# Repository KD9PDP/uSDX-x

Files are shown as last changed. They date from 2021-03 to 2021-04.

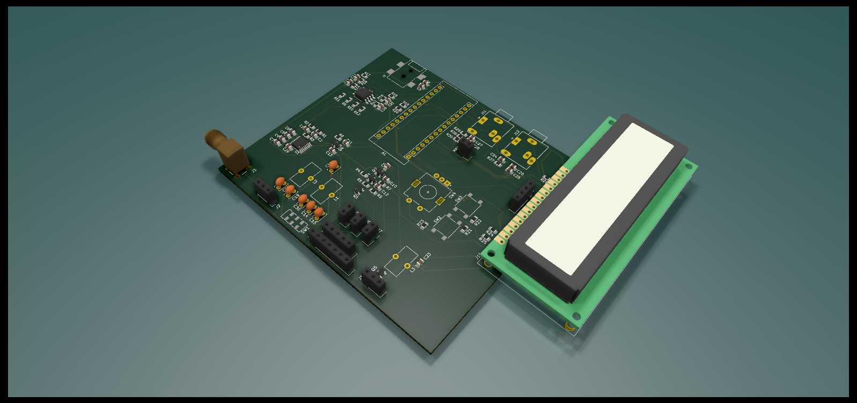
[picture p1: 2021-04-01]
uSDX-x.png

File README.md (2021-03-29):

# uSDX-x
uSDX-x: Microcontroller SDR QRP Transceiver Designed for Experimentation

The goal of this project is to make an uSDX platform that:
* Is Open Hardware Licensed: [TAPR Open Hardware License](https://tapr.org/the-tapr-open-hardware-license/)
* Is modular such that you can use the default on board components or easily add your own
  * Default 1 band on board, but can also add on filter modules for other bands (can experiment with filter modules)
  * Either a 1602 LCD or any LCD using I2C/TWI (e.g., OLED)
  * On board single PA MOSFET or connector for your own experimental evaluation of different MOSFETs (e.g., 3x parallel BS170s)
* Exposes all the key nodes in a way that you can just plug in an Arduino nano module to control them, or you can experiment with other MCU development boards (e.g., 32-bit MCU from various manufacturers such as ARM Cortex-M based MCUs).
* "Semiconductor shortage friendly" (uses si5351 modules instead of chips, which are sold out everywhere until 2022)
  * Contains connectors both for the Adafruit and Etherkit style si5351 modules.
* Compatible with jlcpcb PCBA for low-cost PCB manufacturing and assembly
  * Maximize usage of "basic" parts (e.g., uses a BJT gate driver instead of a 74ACT logic gate driver, possibly with improved performance. NE5532 for the AF op amp instead of LM4562.)

This is based on and compatible with:
https://github.com/threeme3/QCX-SSB
by Guido (PE1NNZ)

For more info on development of uSDX platforms, see: https://groups.io/g/ucx

Two other excellent boards:
https://groups.io/g/ucx/wiki/23416 by Barbaros Asuroglu (WB2CBA)
and
https://dl2man.de/ by Manual (DL2MAN)

Copyright 2021
Scott Howard KD9PDP

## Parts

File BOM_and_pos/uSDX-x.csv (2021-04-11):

Comment | Designator | Footprint | LCSC
Arduino Nano | A1 | Module:Arduino_Nano | no assembly
10n | C2,C11,C12,C13,C27 | Capacitor_SMD:C_0805_2012Metric_Pad1.15x1.40mm_HandSolder | C1710
150p | C14 | Capacitor_THT:C_Disc_D3.8mm_W2.6mm_P2.50mm | no assembly
56p | C15 | Capacitor_THT:C_Disc_D3.8mm_W2.6mm_P2.50mm | no assembly
1n | C16,C17 | Capacitor_SMD:C_0805_2012Metric_Pad1.15x1.40mm_HandSolder | C46653
240p | C18 | Capacitor_THT:C_Disc_D3.8mm_W2.6mm_P2.50mm | no assembly
82p | C19 | Capacitor_THT:C_Disc_D3.8mm_W2.6mm_P2.50mm
220p | C20 | Capacitor_THT:C_Disc_D3.8mm_W2.6mm_P2.50mm | no assembly
10u | C3,C24 | Capacitor_SMD:C_0805_2012Metric_Pad1.15x1.40mm_HandSolder | C15850
200p | C30 | Capacitor_THT:C_Disc_D3.8mm_W2.6mm_P2.50mm | no assembly
100n | C1,C4,C5,C10,C21,C22,C23,C25,C26,C28,C29 | Capacitor_SMD:C_0805_2012Metric_Pad1.15x1.40mm_HandSolder | C49678
470n | C6,C7,C8,C9 | Capacitor_SMD:C_0805_2012Metric_Pad1.15x1.40mm_HandSolder | C13967
DC Jack | J1 | uSDX-x:BarrelJack_XKB_DC-005-5A-2.0-SMT_Horizontal | C319134
1602LCD | J10 | Display:WC1602A | no assembly
PJ-324M | J11,J12 | Connector_Audio:Jack_3.5mm_Ledino_KB3SPRS_Horizontal | no assembly
PA MOSFETs | J13 | Connector_PinSocket_2.54mm:PinSocket_1x03_P2.54mm_Vertical | no assembly
FilterConn | J2 | Connector_PinSocket_2.54mm:PinSocket_1x03_P2.54mm_Vertical | no assembly
Antenna | J3 | eec:Molex-73100-0114-0-0-0 | no assembly
Etherkit si5351 | J4 | Connector_PinSocket_2.54mm:PinSocket_1x05_P2.54mm_Vertical | no assembly
EK CLK0 | J5 | Connector_PinSocket_2.54mm:PinSocket_1x02_P2.54mm_Vertical | no assembly
EK CLK1 | J6 | Connector_PinSocket_2.54mm:PinSocket_1x02_P2.54mm_Vertical | no assembly
EK CLK2 | J7 | Connector_PinSocket_2.54mm:PinSocket_1x02_P2.54mm_Vertical | no assembly
Adafruit si5351 | J8 | Connector_PinSocket_2.54mm:PinSocket_1x07_P2.54mm_Vertical | no assembly
SSD1306 OLED and I2C out | J9 | Connector_PinSocket_2.54mm:PinSocket_1x04_P2.54mm_Vertical | no assembly
12T/T37-6 | L1 | Inductor_THT:L_Toroid_Vertical_L10.0mm_W5.0mm_P5.08mm | no assembly
8T/T37-6 | L2 | Inductor_THT:L_Toroid_Vertical_L10.0mm_W5.0mm_P5.08mm | no assembly
22T/FT37-43 | L3 | Inductor_THT:L_Toroid_Vertical_L10.0mm_W5.0mm_P5.08mm | no assembly
Condenser Mic | MK1 | Connector_PinSocket_2.54mm:PinSocket_1x02_P2.54mm_Vertical | no assembly
S9013 | Q1,Q2 | Package_TO_SOT_SMD:SOT-23 | C6749
S9012 | Q3 | Package_TO_SOT_SMD:SOT-23 | C8543
2N7002 | Q4 | Package_TO_SOT_SMD:SOT-23 | C8545
IRLML2060 | Q5 | Package_TO_SOT_SMD:SOT-23 | C67275
82k | R13,R14 | Resistor_SMD:R_0805_2012Metric_Pad1.15x1.40mm_HandSolder | C17840
1k | R3,R8,R19,R20,R22,R24,R25,R26 | Resistor_SMD:R_0805_2012Metric_Pad1.15x1.40mm_HandSolder | C17513
3k3 | R21 | Resistor_SMD:R_0805_2012Metric_Pad1.15x1.40mm_HandSolder | C26010
270R | R27 | Resistor_SMD:R_0805_2012Metric_Pad1.15x1.40mm_HandSolder | C17590
47R | R4 | Resistor_SMD:R_0805_2012Metric_Pad1.15x1.40mm_HandSolder | C17561
22R | R5 | Resistor_SMD:R_0805_2012Metric_Pad1.15x1.40mm_HandSolder | C17958
10k | R1,R2,R6,R7,R15,R16,R17,R18,R23,R28,R29,R30 | Resistor_SMD:R_0805_2012Metric_Pad1.15x1.40mm_HandSolder | C17414
100R | R9,R10,R11,R12 | Resistor_SMD:R_0805_2012Metric_Pad1.15x1.40mm_HandSolder | C17408
SW_DPDT_x2 | SW1 | Button_Switch_SMD:SW_DPDT_CK_JS202011JCQN | C145844
L | SW2 | Button_Switch_SMD:SW_Push_1P1T_NO_6x6mm_H9.5mm | C480275
R | SW3 | Button_Switch_SMD:SW_Push_1P1T_NO_6x6mm_H9.5mm | C480275
Rotary Encoder | SW4 | Rotary_Encoder:RotaryEncoder_Alps_EC11E-Switch_Vertical_H20mm | no assembly
SN74CBT3253PWR | U1 | Package_SO:TSSOP-16_4.4x5mm_P0.65mm | C424399
NE5532DR | U2 | Package_SO:SOIC-8_5.275x5.275mm_P1.27mm | C7426

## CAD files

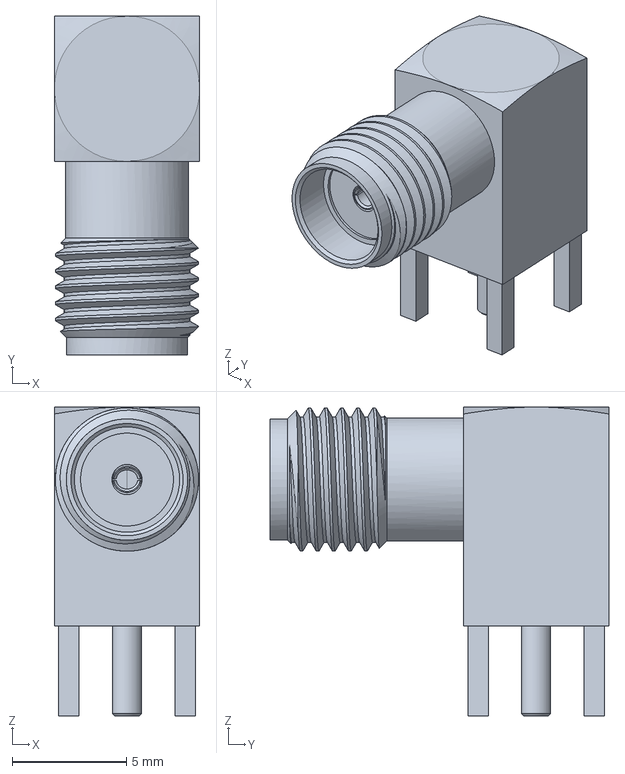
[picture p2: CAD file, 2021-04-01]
extraLibs/eec.models/Molex_-_73100-0114_ssh.stp
6.35 x 14.8 x 13.5 mm

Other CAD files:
extraLibs/eec.models/Molex_-_73100-0114.step

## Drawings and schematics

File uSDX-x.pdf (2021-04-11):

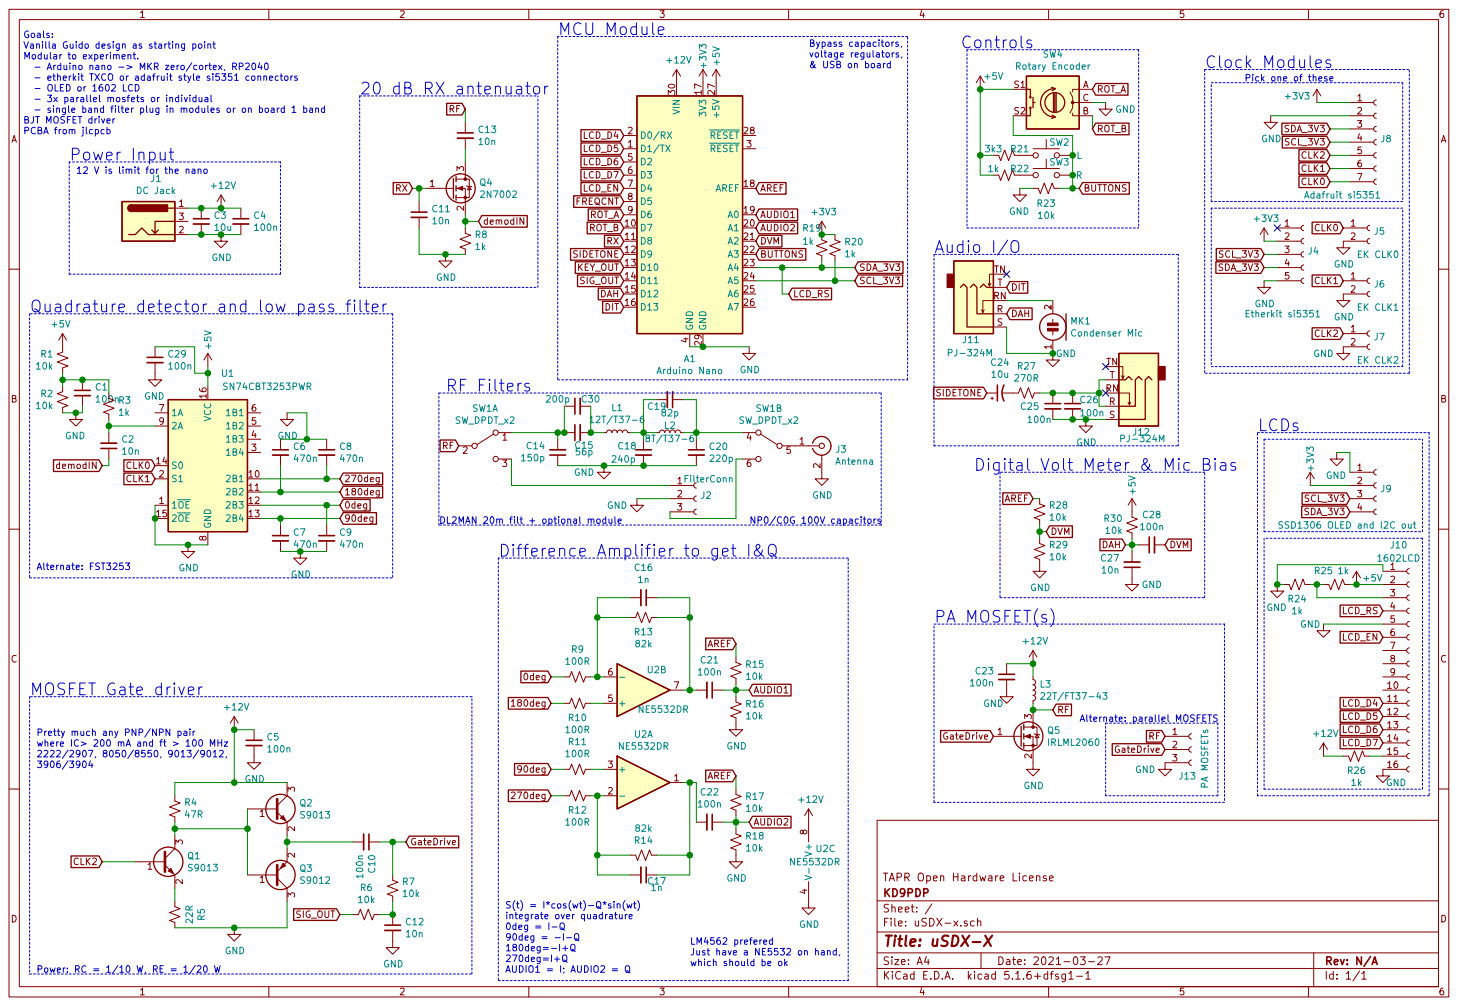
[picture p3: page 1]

LCD_EN Goals: Vanilla Guido design as starting point
2N7002 GND

Modular to experiment.
- Arduino nano -> MKR zero/cortex, RP2040
- etherkit TXCO or adafruit style si5351 connectors
- OLED or 1602 LCD
- 3x parallel mosfets or individual
- single band filter plug in modules or on board 1 band BJT MOSFET driver PCBA from jlcpcb

Just have a NE5532 on hand, which should be ok Quadrature detector and low pass filter

J9 SSD1306 OLED and I2C out GND

AUDIO1 = I; AUDIO2 = Q Difference Amplifier to get I&Q

TAPR Open Hardware License
File: uSDX-x.sch Sheet: / KD9PDP

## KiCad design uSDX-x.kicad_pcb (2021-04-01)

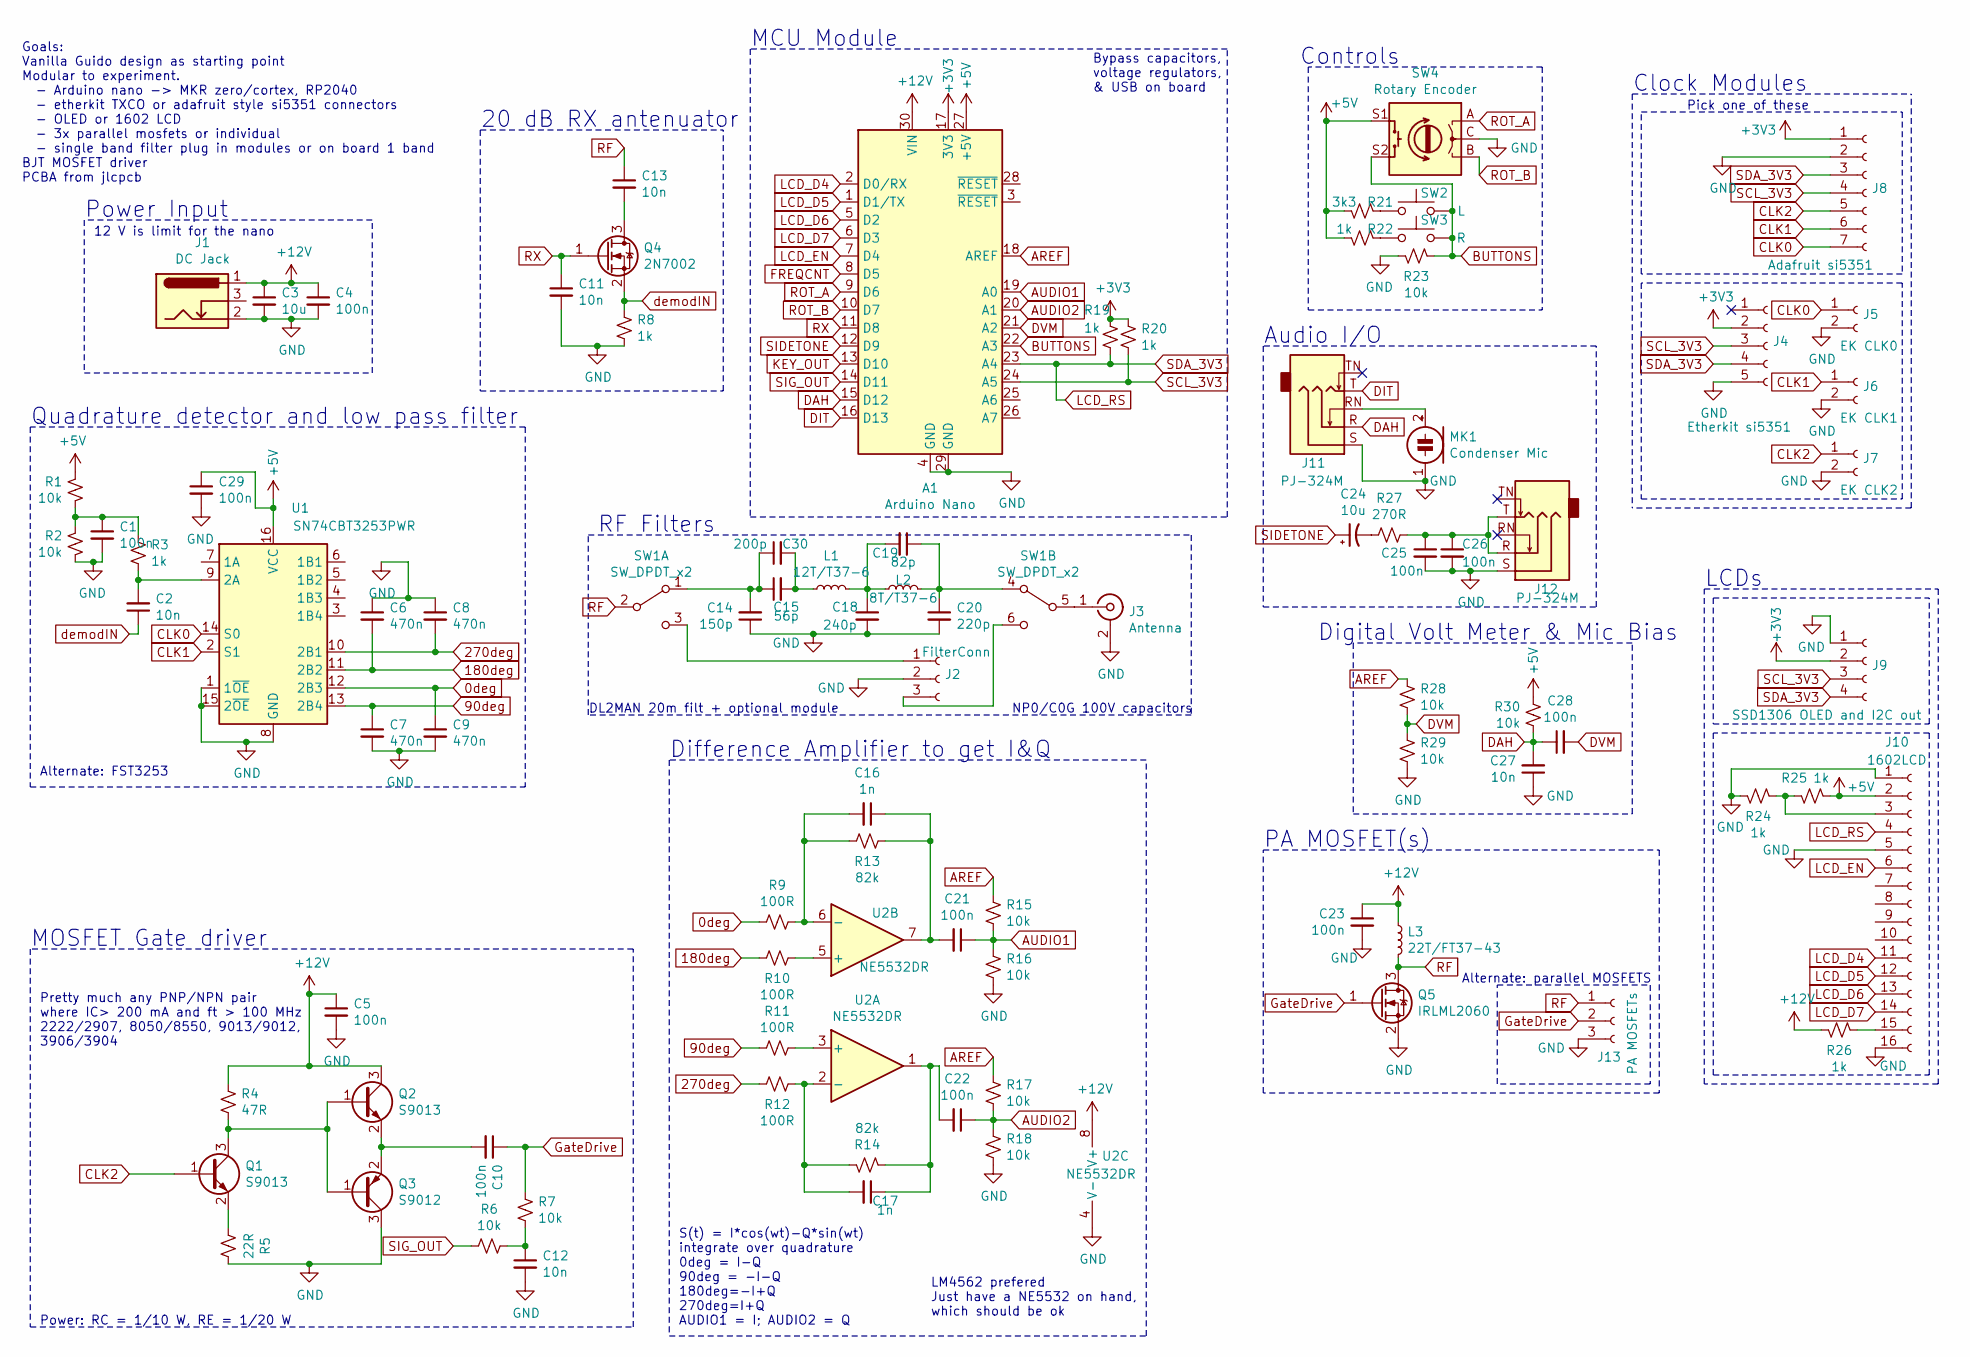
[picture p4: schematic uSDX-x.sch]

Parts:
A1: Arduino Nano; Arduino_Nano; LCSC no assembly
C1, C4, C5, C10, C21, C22, C23, C25, C26, C28, C29: 100n; C_0805_2012Metric_Pad1.15x1.40mm_HandSolder; LCSC C49678
C2, C11, C12, C13, C27: 10n; C_0805_2012Metric_Pad1.15x1.40mm_HandSolder; LCSC C1710
C3, C24: 10u; C_0805_2012Metric_Pad1.15x1.40mm_HandSolder; LCSC C15850
C6, C7, C8, C9: 470n; C_0805_2012Metric_Pad1.15x1.40mm_HandSolder; LCSC C13967
C14: 150p; C_Disc_D3.8mm_W2.6mm_P2.50mm; LCSC no assembly
C15: 56p; C_Disc_D3.8mm_W2.6mm_P2.50mm; LCSC no assembly
C16, C17: 1n; C_0805_2012Metric_Pad1.15x1.40mm_HandSolder; LCSC C46653
C18: 240p; C_Disc_D3.8mm_W2.6mm_P2.50mm; LCSC no assembly
C19: 82p; C_Disc_D3.8mm_W2.6mm_P2.50mm
C20: 220p; C_Disc_D3.8mm_W2.6mm_P2.50mm; LCSC no assembly
C30: 200p; C_Disc_D3.8mm_W2.6mm_P2.50mm; LCSC no assembly
J1: DC Jack; BarrelJack_XKB_DC-005-5A-2.0-SMT_Horizontal; LCSC C319134
J2: FilterConn; PinSocket_1x03_P2.54mm_Vertical; LCSC no assembly
J3: Antenna; Molex-73100-0114-0-0-0; LCSC no assembly
J4: Etherkit si5351; PinSocket_1x05_P2.54mm_Vertical; LCSC no assembly
J5: EK CLK0; PinSocket_1x02_P2.54mm_Vertical; LCSC no assembly
J6: EK CLK1; PinSocket_1x02_P2.54mm_Vertical; LCSC no assembly
J7: EK CLK2; PinSocket_1x02_P2.54mm_Vertical; LCSC no assembly
J8: Adafruit si5351; PinSocket_1x07_P2.54mm_Vertical; LCSC no assembly
J9: SSD1306 OLED and I2C out; PinSocket_1x04_P2.54mm_Vertical; LCSC no assembly
J10: 1602LCD; WC1602A; LCSC no assembly
J11, J12: PJ-324M; Jack_3.5mm_Ledino_KB3SPRS_Horizontal; LCSC no assembly
J13: PA MOSFETs; PinSocket_1x03_P2.54mm_Vertical; LCSC no assembly
L1: 12T/T37-6; L_Toroid_Vertical_L10.0mm_W5.0mm_P5.08mm; LCSC no assembly
L2: 8T/T37-6; L_Toroid_Vertical_L10.0mm_W5.0mm_P5.08mm; LCSC no assembly
L3: 22T/FT37-43; L_Toroid_Vertical_L10.0mm_W5.0mm_P5.08mm; LCSC no assembly
MK1: Condenser Mic; PinSocket_1x02_P2.54mm_Vertical; LCSC no assembly
Q1, Q2: S9013; SOT-23; LCSC C6749
Q3: S9012; SOT-23; LCSC C8543
Q4: 2N7002; SOT-23; LCSC C8545
Q5: IRLML2060; SOT-23; LCSC C67275
R1, R2, R6, R7, R15, R16, R17, R18, R23, R28, R29, R30: 10k; R_0805_2012Metric_Pad1.15x1.40mm_HandSolder; LCSC C17414
R3, R8, R19, R20, R22, R24, R25, R26: 1k; R_0805_2012Metric_Pad1.15x1.40mm_HandSolder; LCSC C17513
R4: 47R; R_0805_2012Metric_Pad1.15x1.40mm_HandSolder; LCSC C17561
R5: 22R; R_0805_2012Metric_Pad1.15x1.40mm_HandSolder; LCSC C17958
R9, R10, R11, R12: 100R; R_0805_2012Metric_Pad1.15x1.40mm_HandSolder; LCSC C17408
R13, R14: 82k; R_0805_2012Metric_Pad1.15x1.40mm_HandSolder; LCSC C17840
R21: 3k3; R_0805_2012Metric_Pad1.15x1.40mm_HandSolder; LCSC C26010
R27: 270R; R_0805_2012Metric_Pad1.15x1.40mm_HandSolder; LCSC C17590
SW1: SW_DPDT_x2; SW_DPDT_CK_JS202011JCQN; LCSC C145844
SW2: L; SW_Push_1P1T_NO_6x6mm_H9.5mm; LCSC C480275
SW3: R; SW_Push_1P1T_NO_6x6mm_H9.5mm; LCSC C480275
SW4: Rotary Encoder; RotaryEncoder_Alps_EC11E-Switch_Vertical_H20mm; LCSC no assembly
U1: SN74CBT3253PWR; TSSOP-16_4.4x5mm_P0.65mm; LCSC C424399
U2: NE5532DR; SOIC-8_5.275x5.275mm_P1.27mm; LCSC C7426

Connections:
0deg: C9.1, R9.1, U1.12 (2B3)
90deg: C7.1, R11.1, U1.13 (2B4)
180deg: C6.2, R10.1, U1.11 (2B2)
270deg: C8.2, R12.1, U1.10 (2B1)
+3V3: A1.17 (3V3), J4.2, J8.1, J9.2, R19.1, R20.1
+5V: A1.27 (+5V), C29.1, J10.2, R1.1, R21.1, R22.1, R25.1, R30.2, SW4.S1, U1.16 (VCC)
+12V: A1.30 (VIN), C3.1, C4.1, C5.1, C23.1, J1.1, L3.1, Q2.3 (C), R4.2, R26.2, U2.8 (V+)
AREF: A1.18 (AREF), R15.1, R17.1, R28.2
AUDIO1: A1.19 (A0), C21.1, R15.2, R16.1
AUDIO2: A1.20 (A1), C22.1, R17.2, R18.1
BUTTONS: A1.22 (A3), R23.2, SW2.1, SW3.1, SW4.S2
CLK0: J5.1, J8.7, U1.14 (S0)
CLK1: J6.1, J8.6, U1.2 (S1)
CLK2: J7.1, J8.5, Q1.1 (B)
DAH: A1.15 (D12), C27.2, C28.1, J11.R, R30.1
DIT: A1.16 (D13), J11.T
DVM: A1.21 (A2), C28.2, R28.1, R29.2
FREQCNT: A1.8 (D5)
GND: A1.4 (GND), A1.29 (GND), C1.2, C3.2, C4.2, C5.2, C6.1, C7.2, C8.1, C9.2, C11.2, C12.2, C14.1, C18.2, C20.2, C23.2, C25.2, C26.2, C27.1, C29.2, J1.2, J2.2, J3.2 (Ext), J4.5, J5.2, J6.2, J7.2, J8.2, J9.1, J10.1, J10.5, J10.16, J11.S, J12.S, J13.3, MK1.1 (-), Q3.3 (C), Q5.2 (S), R2.2, R5.1, R8.1, R16.2, R18.2, R23.1, R24.2, R29.1, SW4.C, U1.1 (1~OE), U1.8 (GND), U1.15 (2~OE), U2.4 (V-)
GateDrive: C10.1, J13.2, Q5.1 (G), R7.2
KEY_OUT: A1.13 (D10)
LCD_D4: A1.2 (D0/RX), J10.11
LCD_D5: A1.1 (D1/TX), J10.12
LCD_D6: A1.5 (D2), J10.13
LCD_D7: A1.6 (D3), J10.14
LCD_EN: A1.7 (D4), J10.6
LCD_RS: A1.23 (A4), J4.4, J8.3, J9.4, J10.4, R19.2
unnamed: C1.1, R1.2, R2.1, R3.1
unnamed: C2.2, R3.2, U1.9 (2A)
unnamed: C10.2, Q2.2 (E), Q3.2 (E)
unnamed: C12.1, R6.1, R7.1
unnamed: C13.2, Q4.3 (D)
unnamed: C14.2, C15.1, C30.1, SW1.1 (A)
unnamed: C15.2, C30.2, L1.1
unnamed: C16.1, C21.2, R13.2, U2.7
unnamed: C16.2, R9.2, R13.1, U2.6 (-)
unnamed: C17.1, C22.2, R14.2, U2.1
unnamed: C17.2, R12.2, R14.1, U2.2 (-)
unnamed: C18.1, C19.2, L1.2, L2.1
unnamed: C19.1, C20.1, L2.2, SW1.4 (A)
unnamed: C24.2, R27.2
unnamed: C25.1, C26.1, J12.R, J12.T, R27.1
unnamed: J2.1, SW1.3 (C)
unnamed: J2.3, SW1.6 (C)
unnamed: J3.1 (In), SW1.5 (B)
unnamed: J10.3, R24.1, R25.2
unnamed: J10.15, R26.1
unnamed: J11.RN, MK1.2 (+)
unnamed: Q1.2 (E), R5.2
unnamed: Q1.3 (C), Q2.1 (B), Q3.1 (B), R4.1
unnamed: R10.2, U2.5 (+)
unnamed: R11.2, U2.3 (+)
unnamed: R21.2, SW2.2
unnamed: R22.2, SW3.2
RF: C13.1, J13.1, L3.2, Q5.3 (D), SW1.2 (B)
ROT_A: A1.9 (D6), SW4.A
ROT_B: A1.10 (D7), SW4.B
RX: A1.11 (D8), C11.1, Q4.1 (G)
SCL_3V3: A1.24 (A5), J4.3, J8.4, J9.3, R20.2
SIDETONE: A1.12 (D9), C24.1
SIG_OUT: A1.14 (D11), R6.2
demodIN: C2.1, Q4.2 (S), R8.2

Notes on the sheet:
Goals: Vanilla Guido design as starting point Modular to experiment. - Arduino nano -> MKR zero/cortex, RP2040 - etherkit TXCO or adafruit style si5351 connectors - OLED or 1602 LCD - 3x parallel mosfets or individual - single band filter plug in modules or on board 1 band BJT MOSFET driver PCBA fr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
12 V is limit for the nano
Pretty much any PNP/NPN pair where IC> 200 mA and ft > 100 MHz 2222/2907, 8050/8550, 9013/9012, 3906/3904
MOSFET Gate driver
Power Input
PA MOSFET(s)
20 dB RX antenuator
Quadrature detector and low pass filter
S(t) = I*cos(wt)-Q*sin(wt) integrate over quadrature 0deg = I-Q 90deg = -I-Q 180deg=-I+Q 270deg=I+Q AUDIO1 = I; AUDIO2 = Q
Difference Amplifier to get I&Q
Controls
MCU Module
RF Filters
LCDs
LM4562 prefered Just have a NE5532 on hand, which should be ok
Alternate: FST3253
Digital Volt Meter & Mic Bias
Audio I/O
Power: RC = 1/10 W, RE = 1/20 W
NP0/C0G 100V capacitors
DL2MAN 20m filt + optional module
Alternate: parallel MOSFETS
Bypass capacitors, voltage regulators, & USB on board
Pick one of these
Clock Modules

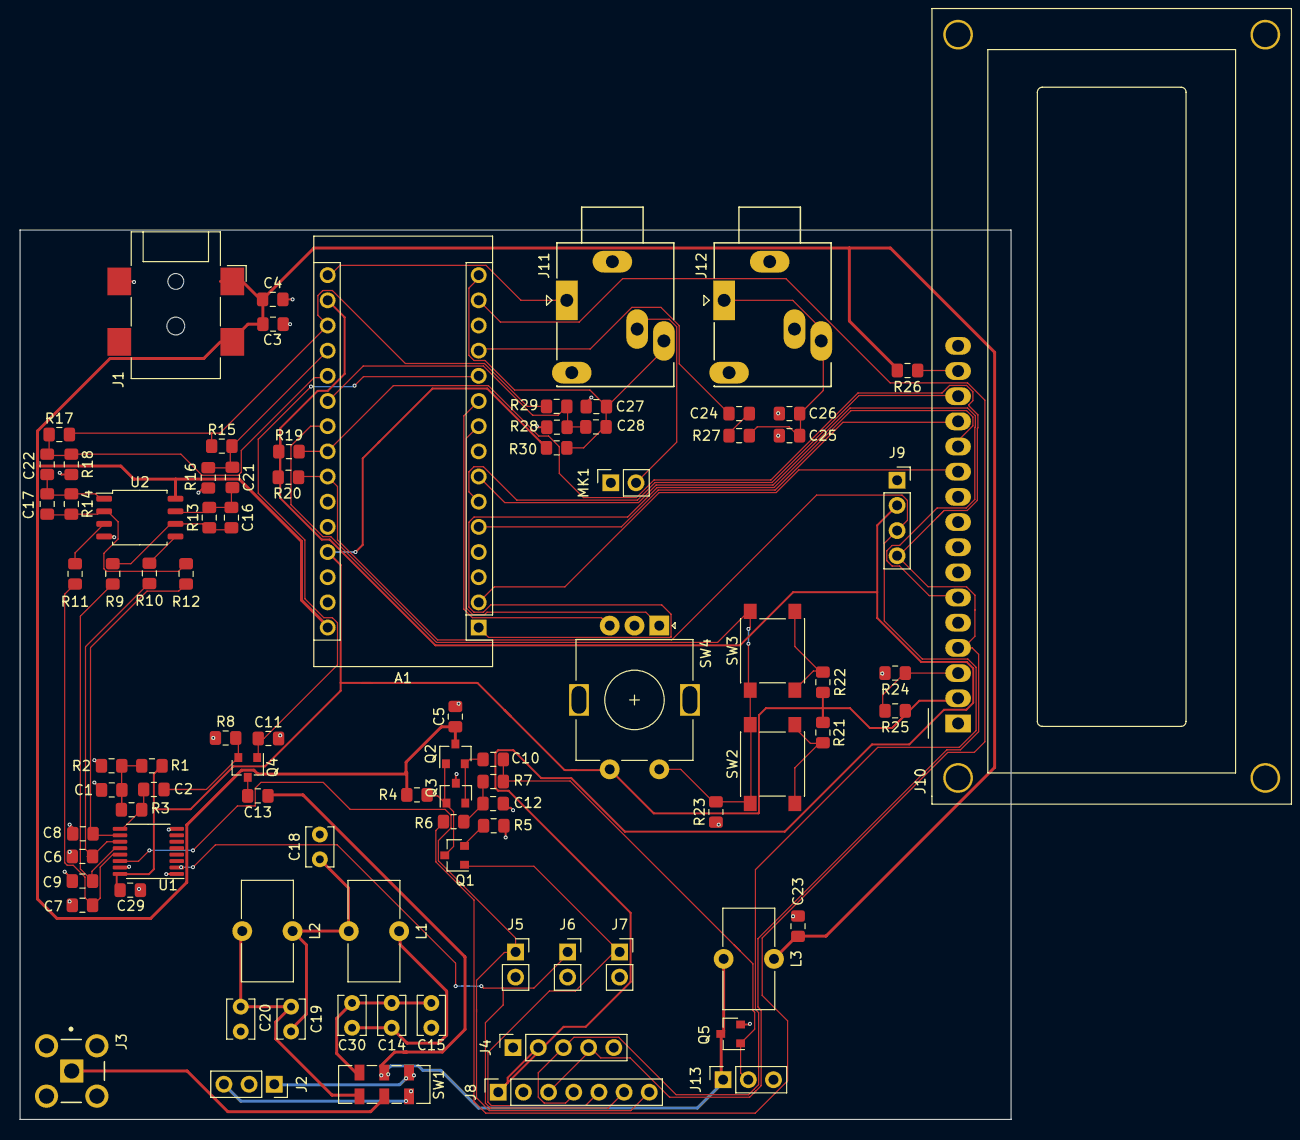
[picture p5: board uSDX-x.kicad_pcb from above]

Board: 2 copper layers, 100.0 x 89.8 mm, 89 parts (0 on the bottom side), 60 nets.

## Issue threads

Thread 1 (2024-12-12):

Prototype made. No display after switch on.

mmagit-it, 2024-12-12:
I've made a prototype of uSDX-x using 1602 display . Unfortunately after switch on display is off.
I've checked all voltages (+12Vdc, +5V, +3.3V) all is ok.
I've programmed Arduino nano with 1.02w and 1.02x versions. Same results.
Any other debugging suggestions are welcome.
Thank you in advance.
Maurizio.
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

maqifrnswa, 2024-12-12:
Sorry, I haven't made it with this MCU and switched over to another
architecture (rp2040 from the raspberry pi pico, a dual core arm cortex m0+
at 125 MHz with integrated USB). That chip architecture was released while
I was working in this repo

See projects doing that here:
https://github.com/ArjanteMarvelde/uSDR-pico
https://github.com/kaefe64/Arduino_uSDX_Pico_FFT_Proj

The rp2040 has programmable IO which can also be used to eliminate the
Si5351

https://github.com/dawsonjon/PicoRX

I switched to the rp2040 because of the programmable input output (PIO) and
dual core MCU helps fix some of the processing audio quality issues.
There's >200KB or RAM, so we can even easily run FreeRTOS on it to control
the interface, and external 16 MB of flash for storing high resolution
waveforms and code.

I haven't seen anyone do it, but I'm working on combining the PIO to
generate the LO_I and LO_Q used in https://github.com/dawsonjon/PicoRX with
the transceiver from https://github.com/ArjanteMarvelde/uSDR-pico would be
pretty cool.

I love the Si5351, but finding clever ways to minimize part counts is fun
too

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

mmagit-it, 2024-12-12:
Thank you Scott for your quick answer. If I have any news I will post them.
Regards.
Maurizio.

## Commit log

2021-03-29 fixed schematic typo in quad detector
    [uSDX-x.sch]
2021-04-01 added first pcb layout and board photo
    [Molex_-_73100-0114.step, Molex_-_73100-0114_ssh.stp, uSDX-x.kicad_pcb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]
2021-04-11 files for first iteration build, some pcb layout improvements
    [uSDX-x-B_Cu.gbr, uSDX-x-B_Mask.gbr, uSDX-x-B_Paste.gbr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]
